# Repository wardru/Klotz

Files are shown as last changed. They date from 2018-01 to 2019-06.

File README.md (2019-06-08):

klotz_logo

Klotz is a small wooden cube that prints informations on a LCD Color screen.

Thanks to two small invisible buttons hidded in the structure, you can switch between different mode such as :

	- Time (Time & Date, Countdown, Stopwatch)
	- Temperature (°C, °F)
	- Rotation angles (X, Y, Z)
	- Game
	- Menu

In the menu, you have access to some parameters such as :

	- Luminosity (8 Levels)
	- Sound (On / Off)
	- Screen rotation (On / Off)
	- Languages (Français, English, Deutsch)
	- Inverted colors (On / Off)

The cube is made of a 3D printed structure, packed in a wooden case.

Klotz is run by a Microchip PIC32 microcontroller, and carries a MPU-6050 gyroscope.

Softwares used to achieve the project :

	- MPLAB/Vim (Code and compilation)
	- Altium (Electrical schematics and PCB Design)
	- Blender (3D)
	- Illustrator/GIMP (all the pictures on klotz have been created by hand)

This project was made as a school project at 42 in a period of 6 months, from February 2017 to July 2017.

Grade : 130/100

Realized by :

	- Patrick Heutschi (Mechanics / Design)
	- Michael Heutschi (Firmware / Packaging construction / Testing)
	- Antoine Gouby (Lead / Hardware / Firmware)

Thanks to 42 and Gregoire (our teacher).

klotz_picture
klotz_slide
pcb_screeshots
pcb2d_screenshot

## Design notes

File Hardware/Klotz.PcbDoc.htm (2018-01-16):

Reporting Options

# File in Previous Format

Date | : | 1/16/2018
Time | : | 5:31:33 AM
Filename | : | C:\Users\Antoine\Desktop\Klotz_altium\Klotz.PcbDoc

Version | Warning

This file was generated by an earlier version of the software

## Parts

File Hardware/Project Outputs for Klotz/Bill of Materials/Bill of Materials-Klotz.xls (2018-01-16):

Klotz BOM
Quantity | LogicalDesignator | Comment | Footprint | Description | Fabricant | Ref. Fabricant | Fournisseur | Ref. Fournisseur
3 | C1, C5, C6 | 100nF | CAPACITOR | Capacitor
2 | C2, C3 | 47pF | CAPACITOR | Capacitor
2 | C4, C7 | 22pF | CAPACITOR | Capacitor
3 | C8, C10, C12 | 10uF | CAPACITOR | Capacitor
1 | C9 | 1uF | CAPACITOR | Capacitor
1 | C11 | 4.7uF | CAPACITOR | Capacitor
3 | D1, D2, D3 | STPS1L30U | Schottky | Diode Schottky | STMICROELECTRONICS | STPS1L30U | Farnell | 1467550
1 | G1 | MPU-6050 Board |  | MPU-6050 Board | InvenSense | MPU-6050 | Olimex | MOD-MPU6050
4 | J1, J1, P1, P2 | Header 2 | Header 2 pins | Header 2 | MULTICOMP | 2211S-02G | Farnell | 1593411
1 | J2 | TFT Connector | SCREEN | TFT Connector | OMRON ELECTRONIC COMPONENTS | XF2M30151A | Farnell | 1112560
1 | J3 | KPEG242 | BUZZER | Buzzer | KINGSTATE | KPEG242 | Farnell | 1502726
1 | J4 | Connector MPU-6050 | GYROSCOPE | Connector MPU-6050 | WURTH ELEKTRONIK | 61301021021 | Farnell | 1841231
1 | J5 | AD22103KTZ | TEMP | Temp sensor | Analog Devices | AD22103KTZ | Farnell | 1438415
1 | J6 | DEBUGGER | DEBUG | DEB Connector | Molex | 22-27-2061 | Farnell | 9731172
1 | L1 | 2.2uH | Inductor | Inductor | WURTH ELEKTRONIK | 744772022 | Farnell | 2211697
2 | Q1 | BSS84 | TRANSISTOR | Transistor | DIODES INC. | BSS84-7-F | Farnell | 1843716
2 | R1 | 10K | Resistor | Resistor
3 | R2, R6, R8 | 1k | Resistor | Resistor
1 | R3 | 4.7k | Resistor | Resistor
1 | R4 | 1MOhm | Resistor | Resistor
1 | R5 | 500K | Resistor | Resistor
1 | R7 | 100K | Resistor | Resistor
1 | S1 | TFT screen |  | TFT screen | MIDAS | MCT0144C6W128128PML | Farnell | 2606862
1 | U1 | PIC32MX170F256B | PIC32 | PIC32 | MICROCHIP | PIC32MX170F256B-I/SO | Farnell | 2449077
1 | U2 | RT8008GB | REGULATEUR | Voltage Regulator | RICHTEK | RT8008GB | Farnell | 2362964
1 | Y1 | 8MHz | OSC1 | Crystal Oscillator | IQD FREQUENCY PRODUCTS | LFXTAL003156 | Farnell | 9712844
1 | Y2 | 32.768KHz | OSC2 | Crystal Oscillator | RALTRON | R26-32.768- 12.5 | Farnell | 1652573

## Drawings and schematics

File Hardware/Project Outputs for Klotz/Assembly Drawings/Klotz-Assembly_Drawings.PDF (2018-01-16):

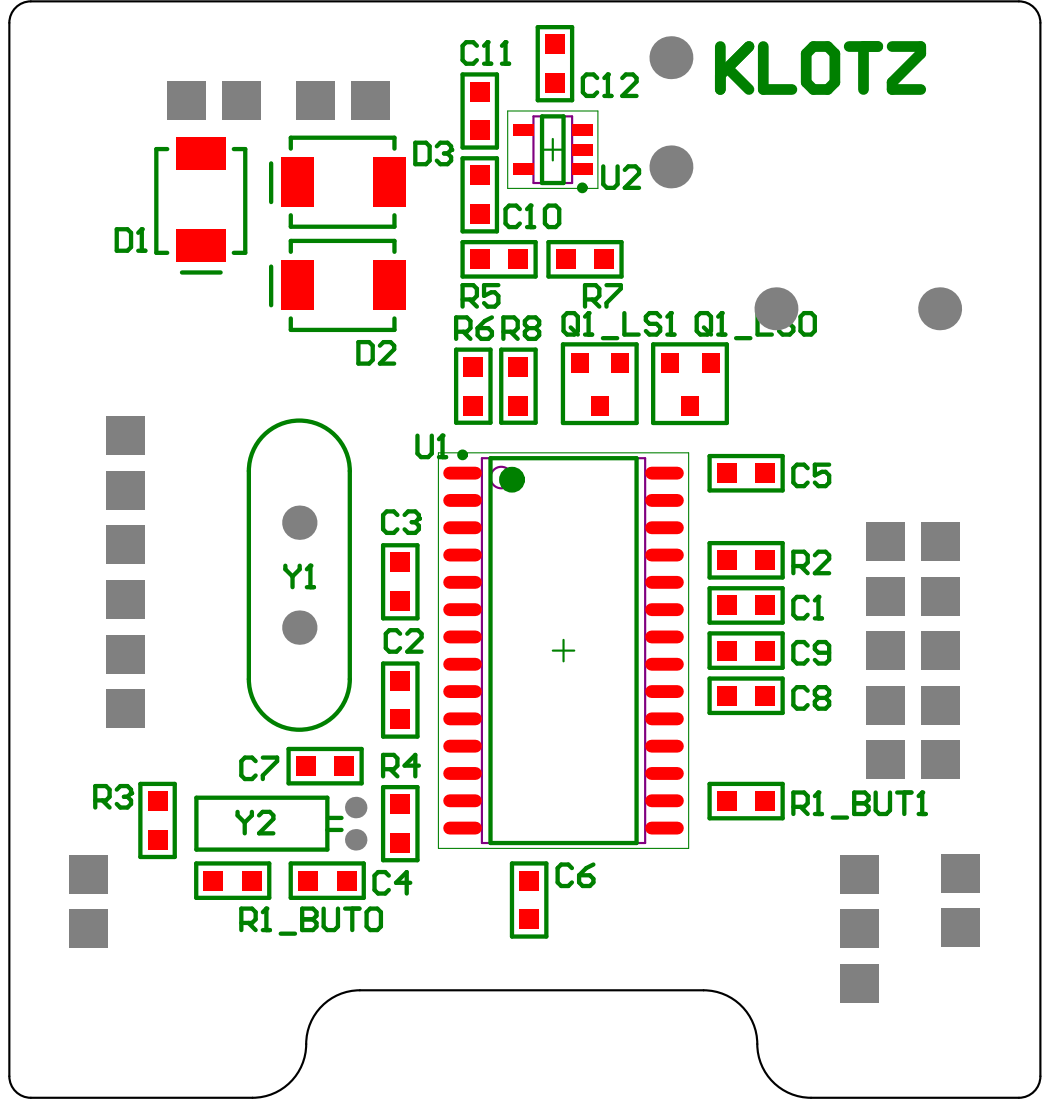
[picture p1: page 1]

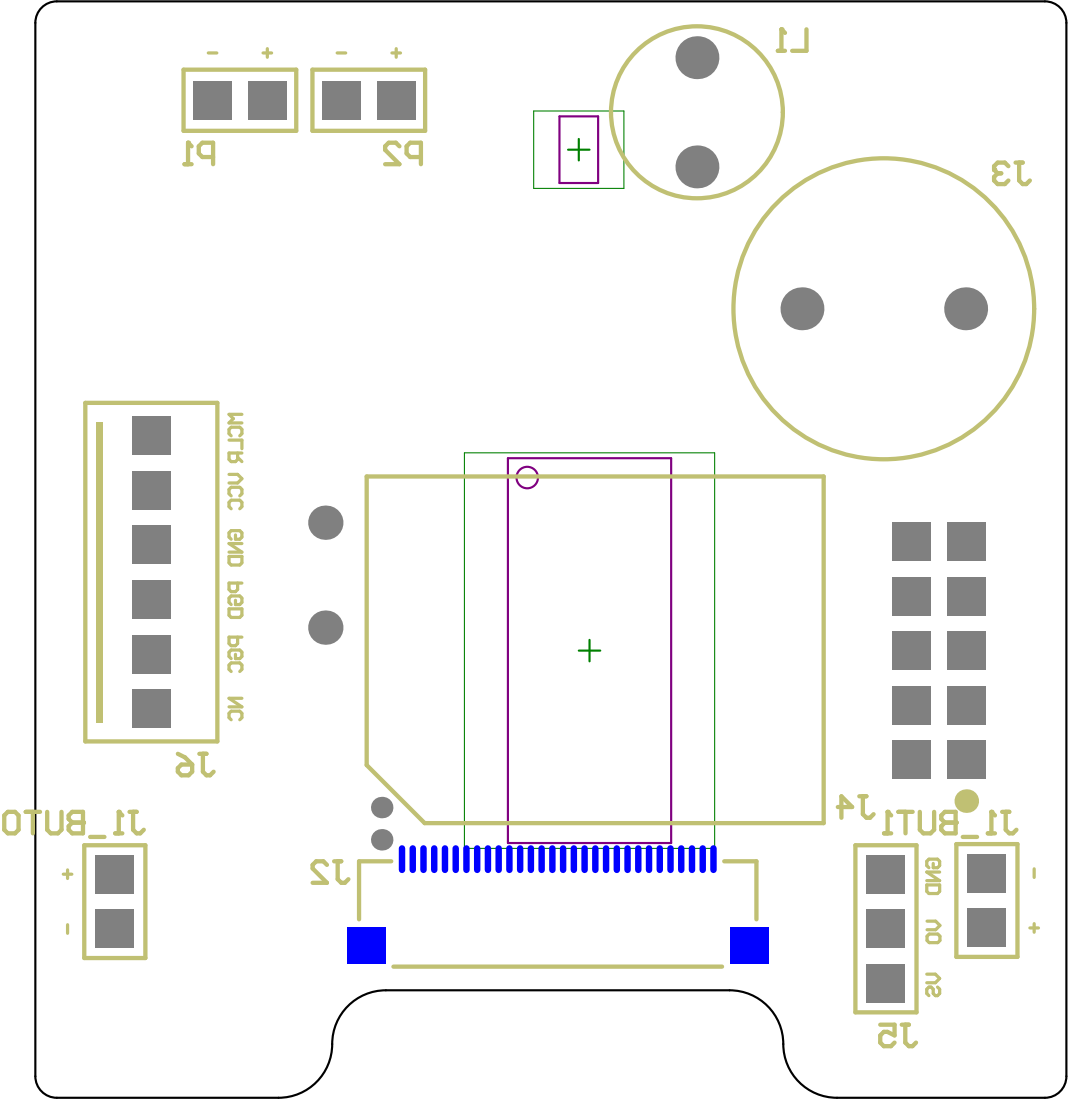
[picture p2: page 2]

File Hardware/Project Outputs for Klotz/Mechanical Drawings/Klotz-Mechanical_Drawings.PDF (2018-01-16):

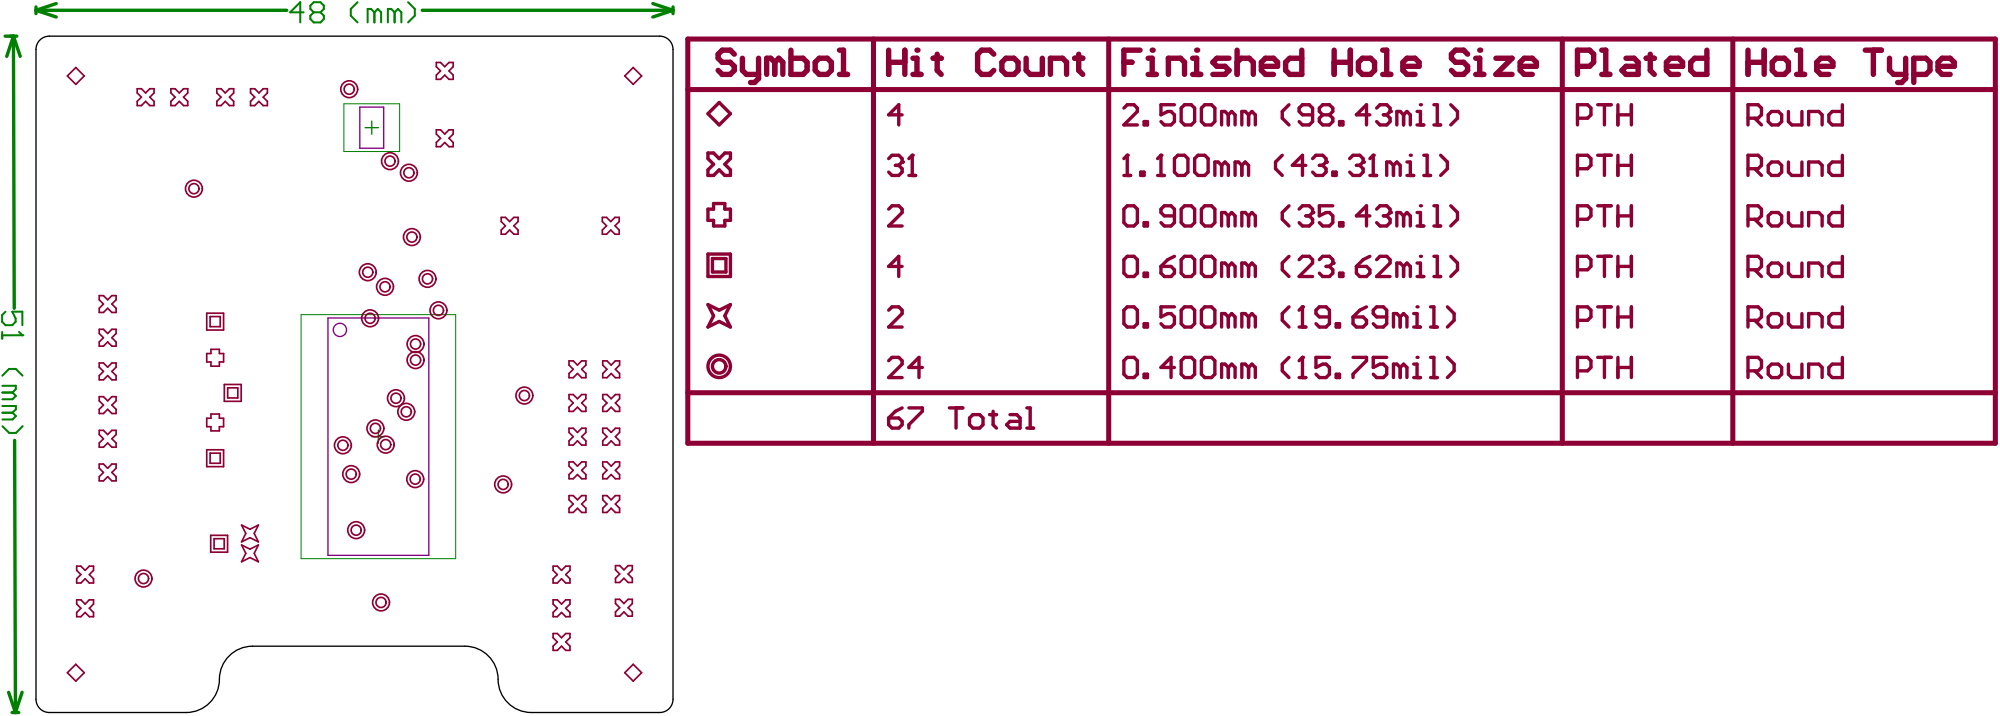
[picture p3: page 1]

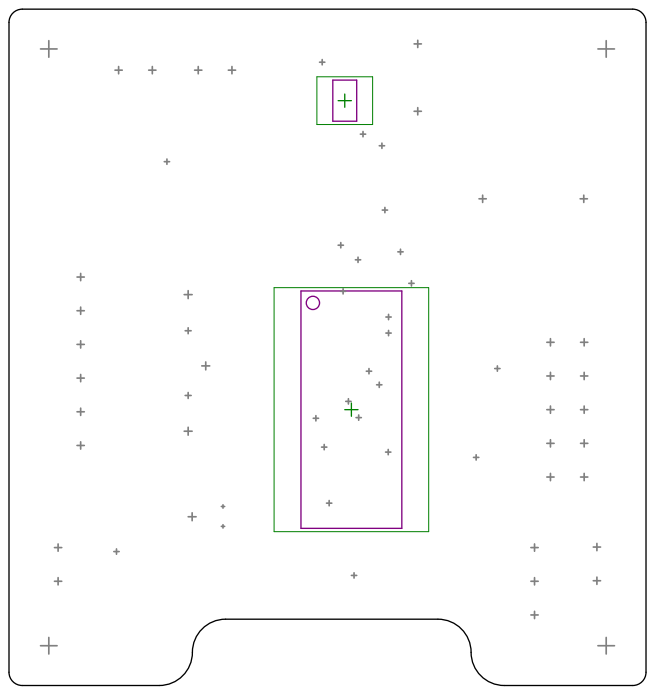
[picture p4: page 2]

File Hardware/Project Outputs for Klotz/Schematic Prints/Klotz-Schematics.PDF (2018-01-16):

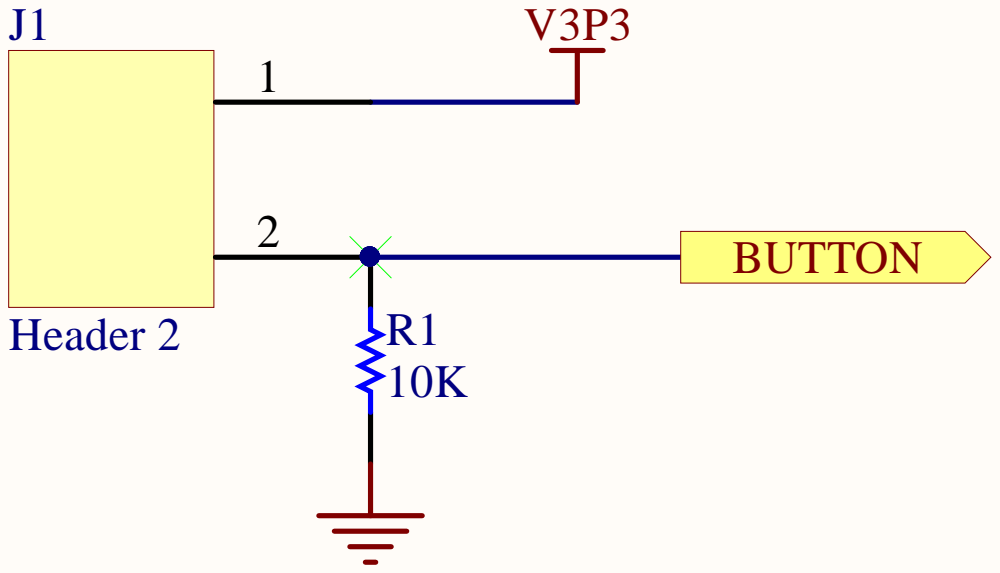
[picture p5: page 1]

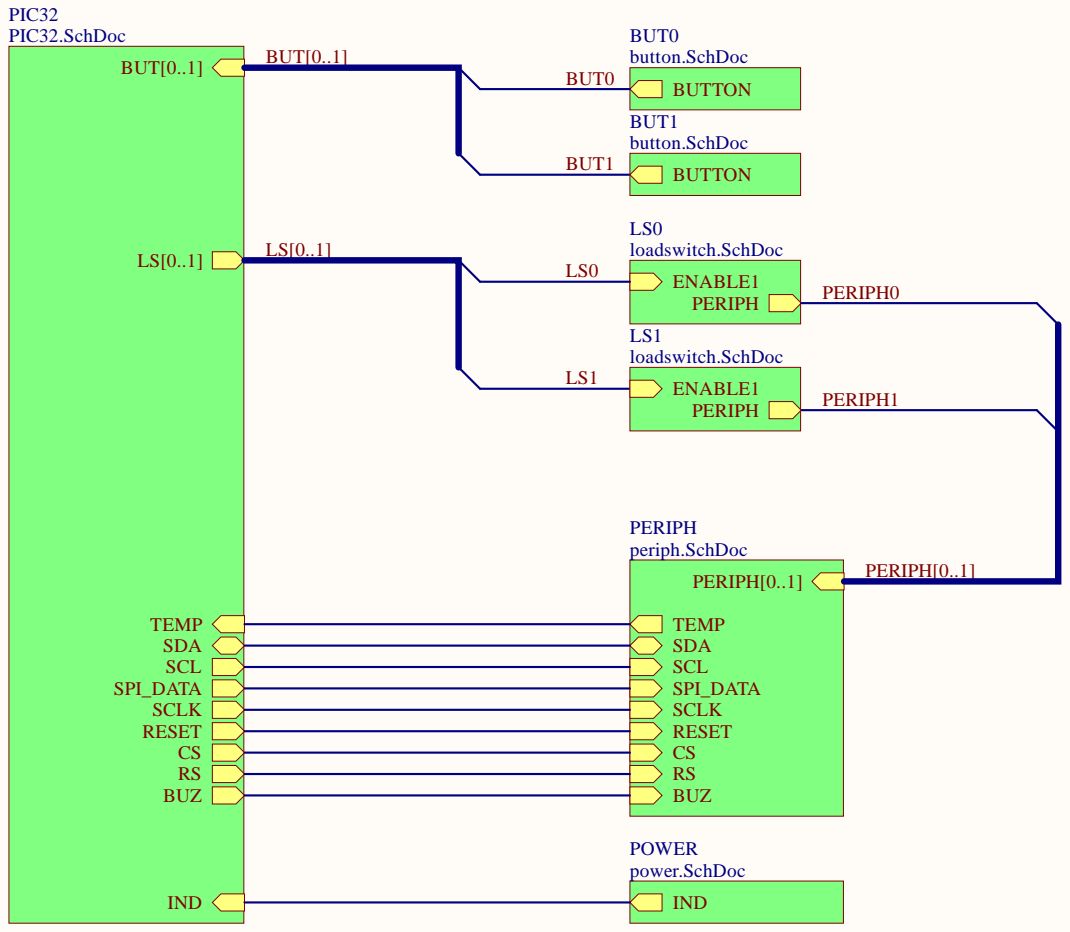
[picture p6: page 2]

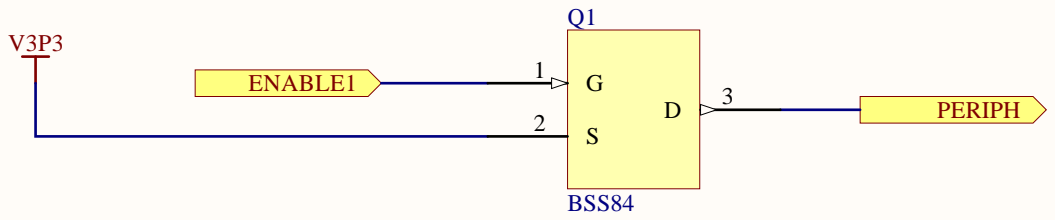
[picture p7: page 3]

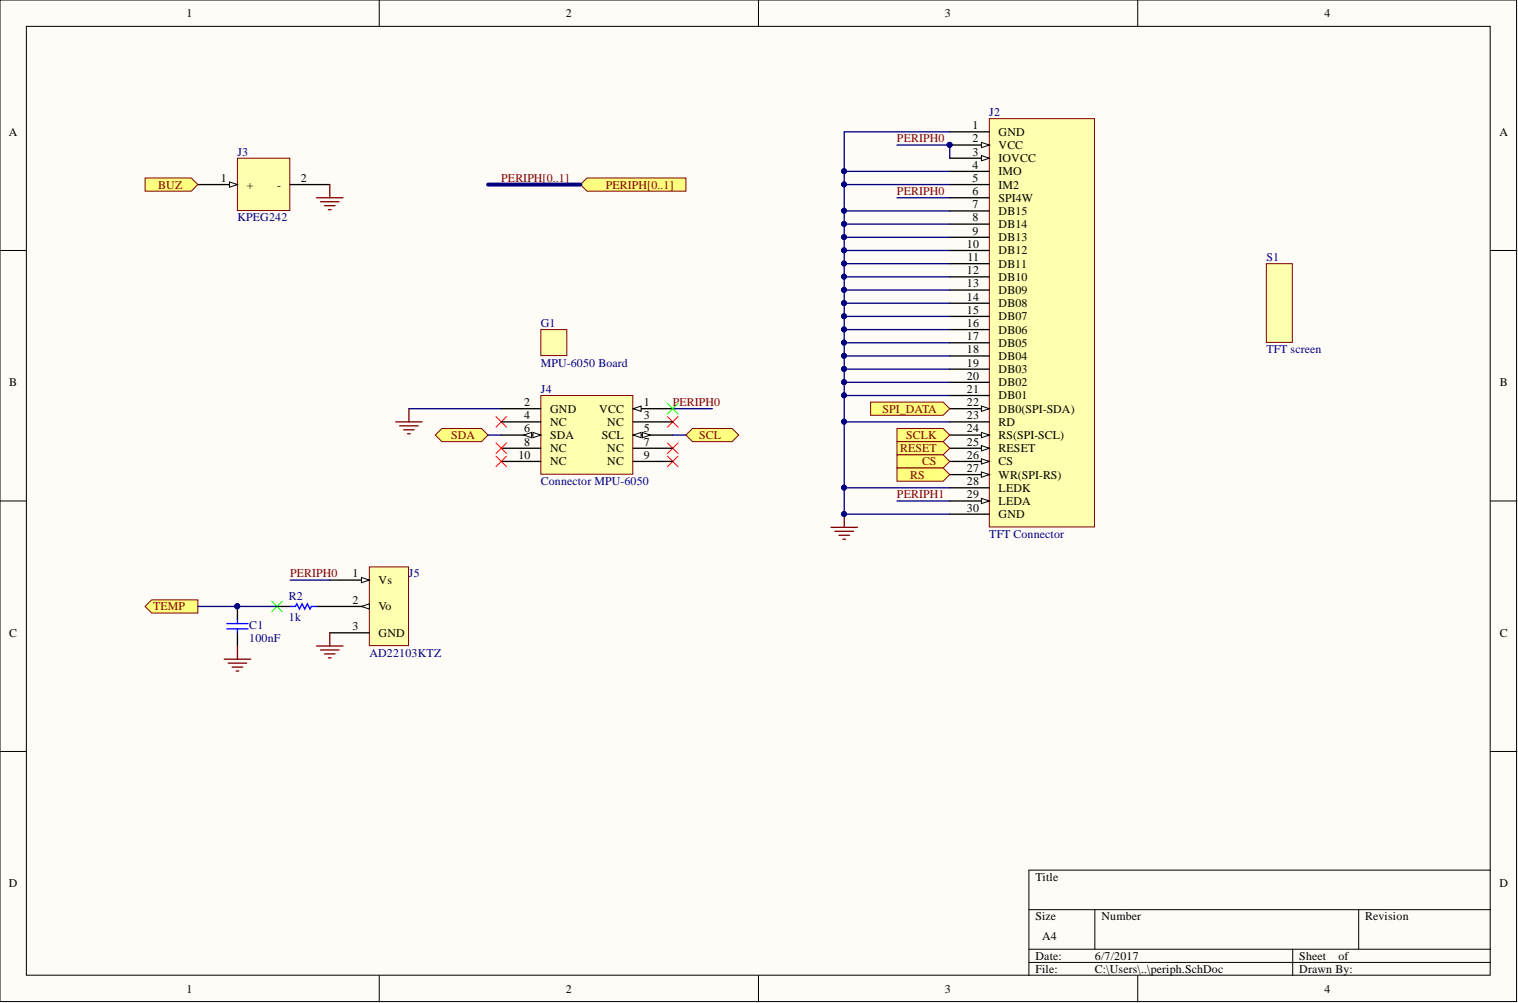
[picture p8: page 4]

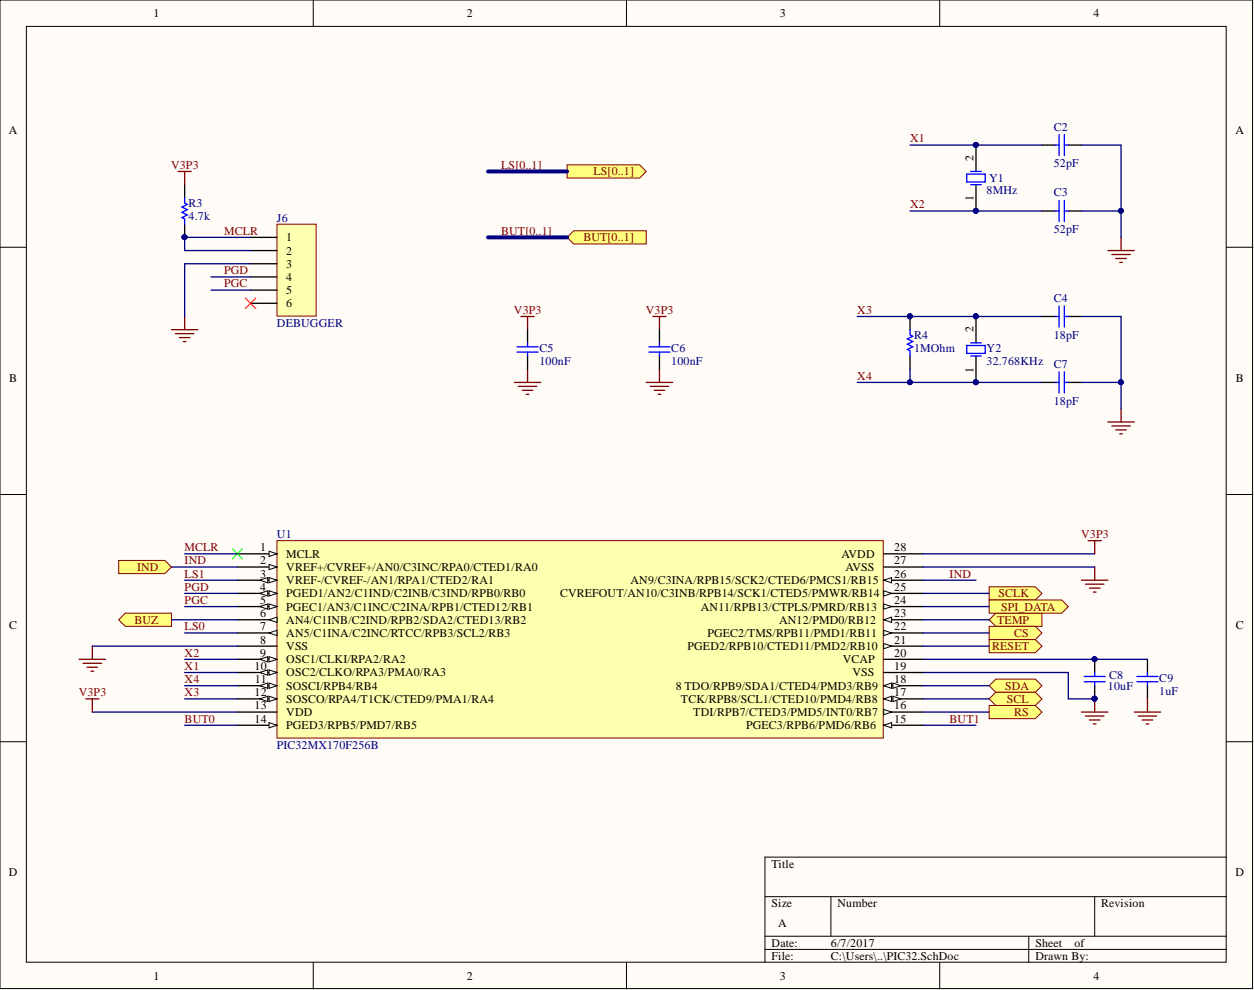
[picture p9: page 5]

1 9
1 8 | SD A

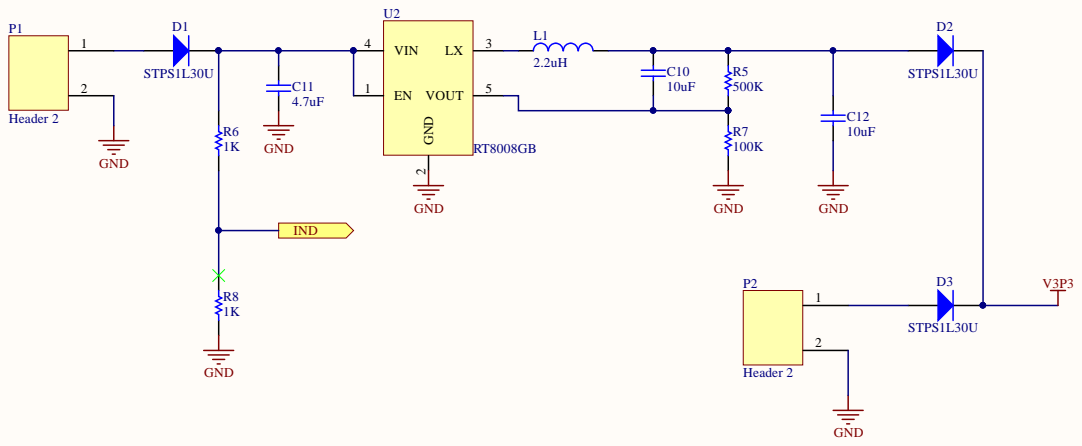
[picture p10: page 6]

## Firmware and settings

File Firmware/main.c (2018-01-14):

#include "klotz.h"

s8 mode;

 void   __ISR(_CHANGE_NOTICE_VECTOR, IPL3SOFT) ChangeNotice_Handler(void)
 { 
//    u32 port = PORTB; // clear port mismatch
    PORTB; // clear port mismatch

    IFS1bits.CNBIF = 0; //CLEAR CNB Interrupt FLAG
 } 
 
 void   __ISR(_COMPARATOR_3_VECTOR, IPL3SOFT)Cmp3_IntHandler(void)
{
    IFS1bits.CMP3IF = 0; // Clear the CMP3 interrupt flag
}

void    activate_periph(void)
{
    PMD1 = 0xFFFFEFFE;
    PMD2 = 0xFFFFFFFB;
    PMD3 = 0xFFFDFFFF;
    PMD4 = 0;
    PMD5 = 0xFFFEFEFF;
    PMD6 = 0xFFFFFFFE;
}

int     main(void)
{
    u16 trig;
    
    trig = 0;
    
    init_pins();
    init_arrays();
    activate_periph();
    init_protocols();
    init_variables(TRUE);
    print_logo_mode();
    while (1)
    {     
//        if (!CM3CONbits.COUT)
//            sleep();
        if (I0b.T1IF)                                   // 1ms timer
        {
            PR1 = 625;
            I0b.T1IF = 0;
            alarm();
            calc_count();
            calc_stop();
        }
        if (I0b.T5IF)                                   // 10ms timer
        {
            PR5 = 6250;
            I0b.T5IF = 0;
            if ((but = get_BUT()) && alarm_state && !(alarm_state = 0))
                but = 0;
            if (but == RIGHT_LONG)
            {
                if (mode == MODE_TIME)
                {
                    if (time_set && !(time_set = 0))
                    {
                        if (time_mode == TIME_CLOCK)
                            write_time_and_date();
                        else if (time_mode == TIME_COUNT)
                            write_count();
                    }
                }
                else if (mode == MENU_SET && menu_mode == MENU_INV)
                    print_LCD_window(38, 8, 53, 7, BK_CLR);
                mode = (mode + 1 == MODE_SIZE) ? 0 : mode + 1;
                set_LUM(0);
                if (mode == MODE_TIME + 1)
                    print_LCD_tk(TRUE);
                mode_page[mode]();
                set_LUM(lum_lvl);
            }
            else if (but == LEFT_LONG)
                sleep();
            (mode == MENU_SET) ? menu_loop[menu_mode]() : mode_loop[mode]();
            game_trig = 1;
        }
        if (I0b.T4IF)
        {
            PR4 = 6250;                                 // 40ms timer
            I0b.T4IF = 0;
            calc_GYRO_TEMP();
        }
        if (I0b.T3IF)                                   // 100ms timer
        {
            PR3 = 62500;
            I0b.T3IF = 0;
            gyro_trig = 1;
            temp_trig = 1;
            blink_trig = 1;
            if (!but && rot_state)
                rot_LCD();
        }
        if (clock.SEC01 != RTb.SEC01)                   // 1sec timer
        {
            clock.SEC01 = RTb.SEC01;
            print_LCD_tk(0);
            if (!RTb.SEC01 && !RTb.SEC10 && !RTb.MIN01 && !RTb.MIN10)
            {
                if (!RTb.HR01 && !RTb.HR10)
                {
                    gyr.sum = gyr.temp[TEMP_CUR];
                    gyr.div = 1;
                    gyr.temp[TEMP_AVG] = gyr.sum;
                }
                else if (RTb.HR01 == 3 && !RTb.HR10)
                    cali_GYRO(1);
            }
        }
    }
    return (0);
}

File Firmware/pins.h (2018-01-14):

/*
 *  This .h file gives a fast and easy access to the configuration of the pins.
 */

#ifndef PINS_H
 #define PINS_H

 #define I0b        IFS0bits
 #define I2Cb       I2C1CONbits

 #define TAb        TRISAbits
 #define TBb        TRISBbits
 #define LAb        LATAbits
 #define LBb        LATBbits
 #define PAb        PORTAbits
 #define PBb        PORTBbits

 #define T_CMP      TAb.TRISA0
 #define L_CMP      LAb.LATA0
 #define P_CMP      PAb.PORTA0

 #define T_LS0      TBb.TRISB3                       // peripheric devices
 #define L_LS0      LBb.LATB3
 #define P_LS0      PBb.PORTB3
 #define T_LS1      TAb.TRISA1                       // screen back_light
 #define L_LS1      LAb.LATA1
 #define P_LS1      PAb.PORTA1

 #define T_BUZ      TBb.TRISB2
 #define L_BUZ      LBb.LATB2
 #define P_BUZ      PBb.PORTB2

 #define T_BUT0     TBb.TRISB5
 #define L_BUT0     LBb.LATB5
 #define P_BUT0     PBb.RB5
 #define T_BUT1     TBb.TRISB6
 #define L_BUT1     LBb.LATB6
 #define P_BUT1     PBb.RB6

 #define T_IND      TBb.TRISB15
 #define L_IND      TBb.LATB15
 #define P_IND      TBb.PORTB15

 #define T_SCLK     TBb.TRISB14
 #define L_SCLK     LBb.LATB14
 #define P_SCLK     LBb.PORTB14

 #define T_SPI      TBb.TRISB13
 #define L_SPI      LBb.LATB13
 #define P_SPI      LBb.PORTB13

 #define T_TEMP     TBb.TRISB12
 #define L_TEMP     LBb.LATB12
 #define P_TEMP     PBb.PORTB12

 #define T_CS       TBb.TRISB11
 #define L_CS       LBb.LATB11
 #define P_CS       PBb.PORTB11

 #define T_RESET    TBb.TRISB10
 #define L_RESET    LBb.LATB10
 #define P_RESET    PBb.PORTB10

 #define T_SDA      TBb.TRISB9
 #define L_SDA      LBb.LATB9
 #define P_SDA      PBb.PORTB9

 #define T_SCL      TBb.TRISB8
 #define L_SCL      LBb.LATB8
 #define P_SCL      PBb.PORTB8

 #define T_RS       TBb.TRISB7
 #define L_RS       LBb.LATB7
 #define P_RS       PBb.PORTB7

#endif
